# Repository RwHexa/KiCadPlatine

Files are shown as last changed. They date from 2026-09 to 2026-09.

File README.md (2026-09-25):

# KiCadPlatine — Netzteil 230 V~ → +12 V, vollständig von einer KI entwickelt

Ein KiCad-8-Projekt für ein einfaches Linearnetzteil mit dem Festspannungsregler **7812**.
Das Besondere daran ist nicht die Schaltung — die steht in jedem Lehrbuch — sondern **wie
sie entstanden ist**: Der komplette Entwurf wurde von der KI **Claude** (Anthropic,
über Claude Code) erstellt. Vorgabe war ein einziges Bild.

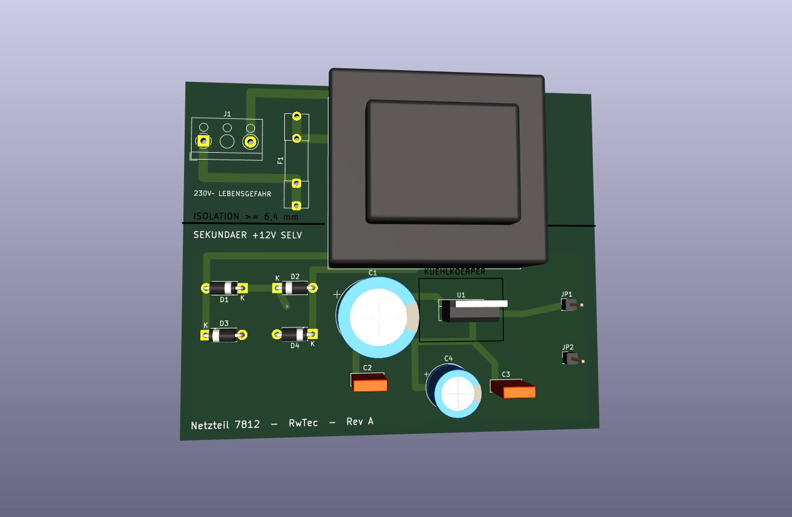
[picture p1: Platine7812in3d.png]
Fertige Platine in der 3D-Ansicht von KiCad


---

## 🤖 Was die KI gemacht hat

**Alles zwischen Vorgabe und fertigen Produktionsdaten — in rund 55 Minuten:**

| Schritt | Ergebnis |
|---|---|
| Bibliotheken analysiert | Symbole und Footprints geprüft statt geraten |
| **Schaltplan** entworfen | 14 Bauteile, 8 Netze, `.kicad_sch` |
| **Bauteilwerte berechnet** | Trafo, Ladeelko, Sicherung, Verlustleistung |
| **Platine layoutet** | Bauteilplatzierung, Primär/Sekundär getrennt |
| **Vollständig geroutet** | 50 Leiterbahnsegmente, nur 2 Durchkontaktierungen |
| **Massefläche** angelegt | bewusst nur sekundärseitig |
| **Sicherheitsregel** definiert | eigene DRC-Regel: 6,4 mm Kriechstrecke |
| **Fehler gefunden und behoben** | u. a. zwei echte Kurzschlüsse |
| **Produktionsdaten** erzeugt | Gerber, Bohrdatei, Stückliste, PDFs |

**Was der Mensch beigetragen hat:** das Vorgabebild, zwei Entscheidungen
(Trafo auf der Platine statt extern, 0,5 A Ausgangsstrom) sowie Durchsicht und Freigabe.
Keine einzige Leiterbahn wurde von Hand gezogen.

Der Entwurf entstand **nicht durch Klicken in der KiCad-Oberfläche**, sondern über
Python-Generatorskripte (`kiutils`, `pcbnew`, `kicad-cli`). KiCad selbst diente als
Prüfinstanz. Das ganze Projekt lässt sich mit einem Befehl reproduzieren:

```bash
python build_all.py
```

## 📋 Die Vorgabe

Mehr als dieses Bild und der Satz *„möchte mit KiCad eine Platine gebaut haben mit
Festspannungsregler 7812 sowie in der Bilddatei beschrieben"* gab es nicht:

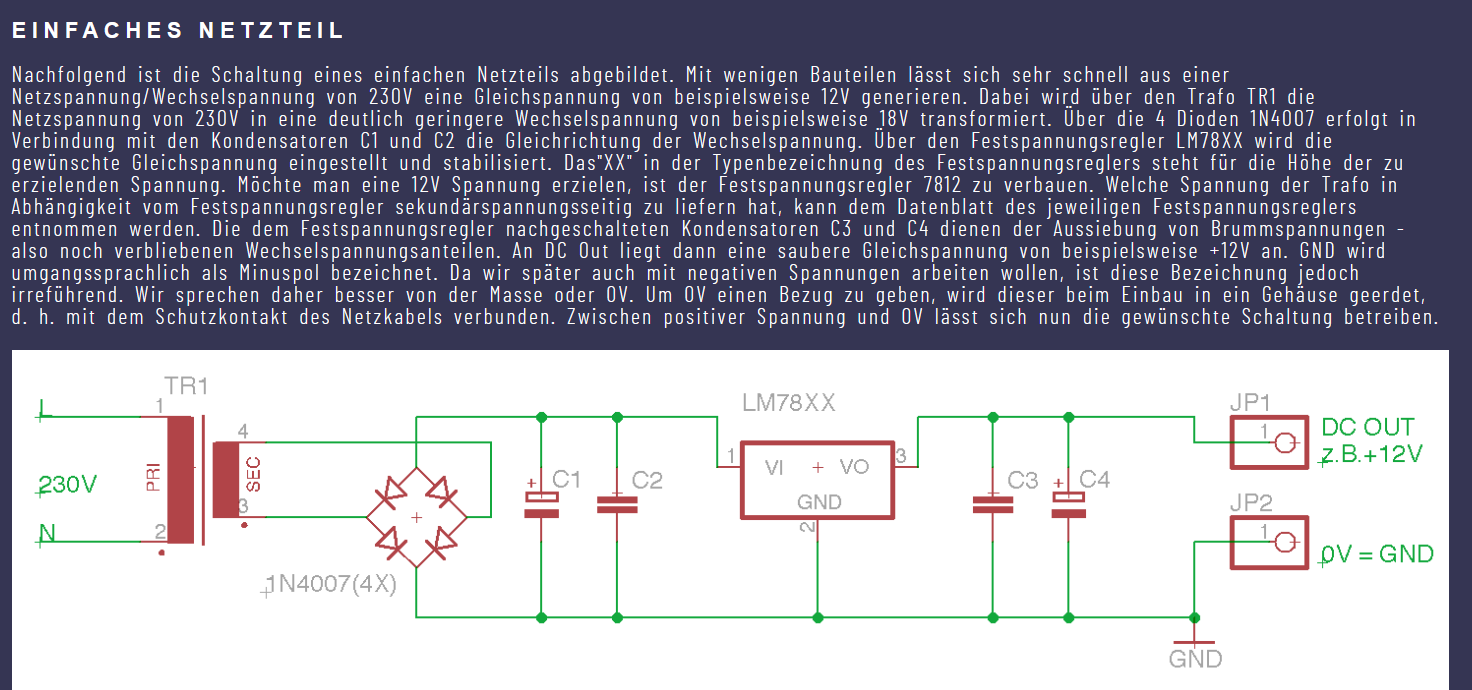
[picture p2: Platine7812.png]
Vorgabe: Schaltbild des einfachen Netzteils


## ✅ Geprüfter Stand

| Prüfung | Ergebnis |
|---|---|
| ERC (Schaltplanprüfung) | **0 Verstöße** |
| DRC (Designregelprüfung) | **0 Verstöße**, 0 unverbundene Anschlüsse |
| Kriechstrecke Primär ↔ Sekundär | **≥ 6,4 mm**, per eigener Regel nachgerechnet |
| Platinengröße | **92,2 × 77,2 mm**, 2 Lagen, bedrahtet (THT) |

Die Prüfberichte [`erc.rpt`](Platine7812/erc.rpt) und [`drc.rpt`](Platine7812/drc.rpt)
liegen im Repository — der Stand ist also nachprüfbar, nicht nur behauptet.

Bewusst unter 100 × 100 mm: Unterhalb dieser Grenze fertigen die üblichen Anbieter
deutlich günstiger. Dafür wanderte die gesamte Sekundärseite unter den Trafo.

## 🔬 Was die KI beim Prüfen gefunden hat

Der interessanteste Teil des Projekts. KiCads Prüfwerkzeuge deckten Fehler auf, die im
Layout wie normale Linien aussehen:

- **Zwei echte Kurzschlüsse** — je eine Leiterbahn lief mitten durch ein fremdes Lötauge
  (Phase durch den Neutralleiter-Anschluss, Masse durch den Reglereingang).
- **Netzlose „Geisterpads"** — der mitgelieferte KiCad-Trafo-Footprint legt 12 Kupferpads
  an, benennt aber nur 4. Die übrigen 8 wären blanke Kupferinseln direkt neben 230 V~
  geworden. Daraus wurde ein eigener, sauberer 4-Pad-Footprint abgeleitet.
- **Zu enge Abstände bei Netzspannung** — die Netzklemme wurde daraufhin von 5,08 mm auf
  10 mm Raster getauscht.

## 💡 Zwei Werte, die von der Vorlage abweichen

Die KI hat nachgerechnet und zwei Angaben des Vorlagentexts bewusst geändert:

**Sekundärspannung 15 V~ statt 18 V~**

```
15 V~ → Scheitelwert 15 · √2                          = 21,2 V
        − 2 Diodenflussspannungen (2 · 0,7 V)         = 19,8 V
        − Brummspannung I·t/C = 0,5 A · 10 ms / 2200 µF = 2,3 V
        → am Reglereingang bleiben                    ≈ 17,5 V
```

Der 7812 braucht mindestens 14 V — 3,5 V Reserve bleiben. Die überschüssige Spannung
verheizt der Regler: mit 15 V~ sind das **3,3 W**, mit 18 V~ wären es **5,5 W** gewesen.

**Trafo 15 VA statt 10 VA** — bei Gleichrichtung mit Ladeelko fließt der Strom in kurzen
Spitzen; der Trafo-Effektivstrom ist rund 1,6…1,8 × der Gleichstrom. Für 0,5 A DC sind das
ca. 0,85 A. Ein 10-VA-Typ liefert bei 15 V nur 0,67 A und wäre überlastet.

## 📦 Inhalt

```
Platine7812/
  Platine7812.kicad_sch     Schaltplan
  Platine7812.kicad_pcb     Leiterplatte, fertig geroutet
  Platine7812.kicad_dru     eigene DRC-Regel (6,4 mm Isolation)
  Platine7812.pretty/       projekteigener Trafo-Footprint
  fertigung/                Gerber, Bohrdatei, ZIP, Stückliste, PDFs
  erc.rpt · drc.rpt         Prüfberichte
  README.md                 technische Doku mit Auslegungsrechnung

  build_all.py              erzeugt das komplette Projekt neu
  build_schematic.py        Schaltplan-Generator
  build_pcb.py              Platinen-Generator (Platzierung + Routing)
  make_trafo_footprint.py   eigener Trafo-Footprint
  setup_project.py          Netzklassen
  make_fabrication.py       Produktionsdateien

PlatineKi.md                Werkstattbericht über die Entstehung
```

Die technischen Details stehen in [`Platine7812/README.md`](Platine7812/README.md),
die Entstehungsgeschichte in [`PlatineKi.md`](PlatineKi.md).

## ⚠️ Sicherheitshinweis

> Die **Primärseite dieser Platine führt Netzspannung (230 V~)**. Nachbau, Inbetriebnahme
> und Messung nur durch entsprechend qualifizierte Personen, mit Trenntrafo und niemals bei
> offenem Gehäuse. Primär- und Sekundärseite sind galvanisch getrennt (SELV am Ausgang).

## 🔧 Vor einem Nachbau zu prüfen

1. **Trafo-Anschlussmaße** gegen das Datenblatt des tatsächlich beschafften 15-VA-Trafos
   abgleichen. Der Footprint ist vom generischen KiCad-Trafo 37 × 44 mm abgeleitet; nach
   oben sind nur 2,4 mm Luft zur Platinenkante.
2. **Kühlkörper** für U1 aussuchen (≤ 15 K/W). Die Fläche von 19 × 14 mm ist freigehalten.
   Ohne Kühlkörper schaltet der 7812 bei 3,3 W thermisch ab.

Das Projekt ist geprüft, aber **noch nicht als Hardware aufgebaut**.

## 📄 Lizenz

[MIT](LICENSE) — die Lizenz gilt für **alle Bestandteile** dieses Repositorys: die
Generatorskripte, die KiCad-Entwurfsdateien und die Produktionsdaten. Nachbauen,
verändern und weitergeben sind ausdrücklich erwünscht, auch kommerziell; der
Copyright-Hinweis muss erhalten bleiben.

Wie in der MIT-Lizenz festgehalten, erfolgt die Weitergabe **ohne jede Gewährleistung**.
Das ist hier mehr als eine Formalie: Die Platine führt Netzspannung und ist bislang
geprüft, aber nicht als Hardware aufgebaut. Wer sie nachbaut, trägt die Verantwortung
für die eigene Ausführung — siehe Sicherheitshinweis oben.

---

*KiCad 8.0.8 · kiutils / pcbnew / kicad-cli · Entwurf: Claude (Anthropic) via Claude Code · Rw*

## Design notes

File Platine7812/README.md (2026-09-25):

# Platine7812 — einfaches Netzteil 230 V~ → +12 V DC

KiCad-8-Projekt nach dem Referenz-Schaltbild: Printtrafo **TR1** → Brücken­gleich­richter
aus **4 × 1N4007** → Siebung **C1/C2** → Festspannungsregler **LM7812** → **C3/C4** →
Ausgangsklemmen **JP1 (+12 V)** und **JP2 (0 V = GND)**.

> ⚠️ **LEBENSGEFAHR:** Die **Primärseite führt Netzspannung (230 V~)**. Primär- und
> Sekundärseite sind galvanisch getrennt (SELV am Ausgang). Aufbau, Inbetriebnahme und
> Messung nur durch qualifizierte Personen, Trenntrafo verwenden, Platine nie offen
> betreiben. Der 0-V-Anschluss wird beim Einbau ins Gehäuse mit dem Schutzkontakt verbunden.

## Stand

| Prüfung | Ergebnis |
|---|---|
| ERC (Schaltplan) | **0 Verstöße** |
| DRC (Leiterplatte) | **0 Verstöße**, **0 unverbundene Pads** |
| Kriechstrecke Primär↔Sekundär | **≥ 6,4 mm**, per eigener DRC-Regel nachgerechnet |
| Platinengröße | **92,2 × 77,2 mm**, 2 Lagen, THT |

Die Platine ist **vollständig geroutet** (50 Leiterbahnsegmente, 2 Durchkontaktierungen)
und hat eine gefüllte Massefläche auf der Rückseite — ausschließlich auf der
Sekundärseite, damit unter den netzspannungsführenden Bahnen kein Kupfer liegt.

## Stückliste

| Ref | Wert | Bauform / Footprint |
|---|---|---|
| TR1 | 230 V / 15 V, **15 VA** | Printtrafo, Körper 37 × 44 mm, 4 Pins |
| F1 | **T 160 mA / 250 V** | Feinsicherung 5 × 20 mm mit Printhalter, hochkant |
| J1 | Netzeingang L/N | Schraubklemme, **10 mm Raster** |
| D1–D4 | 1N4007 | DO-41, liegend, Raster 7,62 mm |
| C1 | 2200 µF / 35 V | Elko radial, Ø 16 mm, Raster 7,5 mm |
| C2 | 100 nF / 100 V | Folie, Raster 5 mm |
| U1 | **LM7812** | TO-220 stehend, **Kühlkörper erforderlich** |
| C3 | 100 nF / 50 V | Folie, Raster 5 mm |
| C4 | 100 µF / 25 V | Elko radial, Ø 10 mm, Raster 5 mm |
| JP1 / JP2 | +12 V / 0 V | je 1 Stift, Raster 2,54 mm |

## Auslegung — warum diese Werte

**Sekundärspannung 15 V~ (nicht 18 V~).** Der Text zum Referenzbild nennt 18 V als
Beispiel. 15 V reichen aber und halbieren fast die Verlustwärme:

```
15 V~ → Scheitelwert      15 · √2        = 21,2 V
        − 2 Diodenflussspannungen (2 · 0,7 V) = 19,8 V
        − Brummspannung  ΔU = I·t/C = 0,5 A · 10 ms / 2200 µF = 2,3 V
        → Minimum am Reglereingang            ≈ 17,5 V
```

Der 7812 braucht mindestens 14 V am Eingang (12 V + 2 V Dropout) — **3,5 V Reserve**.
Verlustleistung am Regler: `(18,6 V − 12 V) · 0,5 A ≈ 3,3 W`.
Mit 18 V~ wären es **5,5 W** gewesen.

**Kühlkörper ist Pflicht.** Bei 3,3 W und 40 °C Umgebung wird ein Kühlkörper mit
**≤ 15 K/W** gebraucht (Sperrschicht bleibt dann bei rund 105 °C). Auf der Platine ist
dafür eine Fläche von **19 × 14 mm** hinter U1 freigehalten und auf der Lage `Dwgs.User`
markiert. Ohne Kühlkörper schaltet der 7812 thermisch ab.

**Trafo 15 VA, nicht 10 VA.** Bei Gleichrichtung mit Ladeelko fließt der Strom in kurzen
Spitzen; der Trafo-Effektivstrom ist rund **1,6…1,8 × der Gleichstrom**. Für 0,5 A DC sind
das ca. 0,85 A — ein 10-VA-Typ liefert bei 15 V nur 0,67 A und wäre überlastet.
15 VA / 15 V = 1,0 A reicht mit Reserve.

**Sicherung.** Primär-Nennstrom `15 VA / 230 V = 65 mA`, träge Sicherung mit etwa dem
doppelten Wert → **T 160 mA**.

## Aufbau der Leiterplatte

**Primärseite oben** (y < 86 mm): J1 → F1 → TR1-Primärwicklung.
**Sekundärseite unten** (y > 90 mm): Brücke → C1/C2 → U1 → C3/C4 → JP1/JP2.
Dazwischen liegt die **Isolationsbarriere**; sie ist auf `Dwgs.User` eingezeichnet und
wird bauartbedingt nur vom Trafo selbst überbrückt (Pin-Reihenabstand 25,4 mm).

**Kreuzungsfreie Brückenanordnung.** D1 und D4 sind um 180° gedreht. Dadurch liegen die
beiden Kathoden (VRAW) innen nebeneinander und die beiden GND-Anoden ebenfalls:

```
AC1 --|<|-- VRAW   VRAW --|<|-- AC2     obere Reihe (D1 gedreht, D2)
AC1 --|<|-- GND    GND  --|<|-- AC2     untere Reihe (D3, D4 gedreht)
```

Die Brücke selbst braucht damit keine einzige Kreuzung. Nur VRAW muss die AC2-Bahn
queren — das erledigen zwei Durchkontaktierungen im freien Korridor zwischen den
Diodenreihen. GND läuft komplett auf der Rückseite und kann deshalb nichts kreuzen.

## Dateien

| Datei | Inhalt |
|---|---|
| `Platine7812.kicad_sch` | Schaltplan |
| `Platine7812.kicad_pcb` | Leiterplatte, geroutet |
| `Platine7812.kicad_pro` | Projektdatei inkl. Netzklassen |
| `Platine7812.kicad_dru` | **eigene DRC-Regel: 6,4 mm Primär ↔ Sekundär** |
| `Platine7812.net` | Netzliste (aus dem Schaltplan erzeugt) |
| `Platine7812.pretty/` | projekteigener Trafo-Footprint |
| `fertigung/` | Gerber, Bohrdateien, ZIP, Stückliste, PDFs |
| `erc.rpt`, `drc.rpt` | Prüfberichte |

### Generatorskripte

Das Projekt wird **vollständig aus Skripten erzeugt**; die Netzliste ist die einzige
Quelle der Wahrheit für die Leiterplatte (kein manueller Netzlisten-Import nötig).

```bash
python build_all.py
```

Das durchläuft der Reihe nach:

| Schritt | Skript | Ergebnis |
|---|---|---|
| 1 | `make_trafo_footprint.py` | Trafo-Footprint + `fp-lib-table` |
| 2 | `build_schematic.py` | `.kicad_sch` |
| 3 | `kicad-cli sch erc` | `erc.rpt` |
| 4 | `kicad-cli sch export netlist` | `.net` |
| 5 | `build_pcb.py` | `.kicad_pcb` (platziert, geroutet, Zone gefüllt) |
| 6 | `setup_project.py` | Netzklassen in `.kicad_pro` |
| 7 | `kicad-cli pcb drc` | `drc.rpt` |

Fertigungsdaten danach mit:

```bash
python make_fabrication.py
```

## Stolpersteine, die hier gelöst sind

1. **`LM7812_TO220` hat keine eigenen Pins** — das Symbol erbt sie per `extends` von
   `LM7805_TO220`. Wird es unverändert eingebettet, zeichnet Eeschema ein leeres Kästchen.
   `build_schematic.py` klopft es flach und schreibt die Unit-Namen um.
2. **Der KiCad-Trafo-Footprint hat Geisterpads.** `Transformer_THT:Transformer_37x44` legt
   12 Kupferpads an, nummeriert aber nur 4. Die 8 netzlosen Pads wären blanke Kupferinseln
   neben 230 V~. `make_trafo_footprint.py` leitet einen sauberen 4-Pad-Footprint ab.
3. **`kicad-cli` überschreibt die `.kicad_pro`** und wirft dabei eigene Netzklassen weg.
   Deshalb läuft `setup_project.py` immer **als letzter Schritt**.
4. **`ZONE_FILLER` stürzt** auf einem frisch erzeugten Board ab (Segfault). Auf einem
   *geladenen* Board mit `BuildConnectivity()` läuft er durch — `build_pcb.py` macht
   deshalb den Umweg Speichern → Laden → Füllen → Speichern. Ohne das bliebe die
   Massefläche in den Gerber-Dateien leer.
5. **Bohrdateien werden nicht mitgeplottet.** `export gerbers` liefert keine `.drl`;
   `make_fabrication.py` ruft `export drill` separat auf und bricht ab, wenn die
   Bohrdatei fehlt — ein ZIP ohne `.drl` ist beim Fertiger unbrauchbar.

## Vor dem Bestellen bitte prüfen

1. **Trafo-Footprint gegen das Datenblatt abgleichen.** Der Footprint ist vom generischen
   KiCad-Trafo 37 × 44 mm abgeleitet: Primärpads bei x = 0 / 20,32 mm, Sekundärpads bei
   x = ±5,08 mm, Reihenabstand 25,4 mm. **Rastermaß und Pinbelegung des tatsächlich
   beschafften Trafos prüfen** und notfalls in `make_trafo_footprint.py` anpassen.
2. **Kühlkörper aussuchen** (≤ 15 K/W) und prüfen, ob er in die freigehaltenen
   19 × 14 mm passt.
3. **Elko-Bauhöhen** gegen das geplante Gehäuse prüfen (C1 ist Ø 16 mm).
4. Die **Sicherung sitzt nur in der Phase (L)**. Für allpolige Trennung gehört ein
   zweipoliger Schalter vor die Platine.

---
*RwTec · 2026 · erstellt mit Claude Code aus dem Referenz-Schaltbild.*

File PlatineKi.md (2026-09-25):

# Platinenentwurf mit KiCad und Claude Code — ein Werkstattbericht

> **Kurzfassung:** Aus einem Schaltbild als Bilddatei ist in rund **55 Minuten** eine
> fertige, geprüfte Leiterplatte geworden: ein Netzteil 230 V~ → +12 V mit dem
> Festspannungsregler 7812. Vorgegeben waren ein Screenshot und ein erklärender Text —
> herausgekommen sind Schaltplan, geroutete Platine (92 × 77 mm, ==ERC 0, DRC 0==) und
> ein vollständiger Satz Produktionsdateien. Besonderheit: Der Entwurf entstand nicht
> durch Klicken in KiCad, sondern über **Generatorskripte**, und KiCad selbst diente als
> Prüfinstanz.

---

## 🧭 Die Vorgabe

Ausgangspunkt war ein Bild mit Schaltung und Beschreibung — das klassische
Lehrbuch-Netzteil:

Vorgabe: Schaltbild des einfachen Netzteils

Der Text dazu beschreibt den Signalweg: Der Trafo **TR1** setzt die Netzspannung von
230 V auf eine kleinere Wechselspannung herunter, vier Dioden **1N4007** richten sie
gleich, **C1/C2** sieben sie, der **LM78XX** stabilisiert auf die gewünschte
Gleichspannung, **C3/C4** bügeln Restbrummen glatt. Heraus kommen an **JP1/JP2** die
+12 V gegen Masse.

Meine Vorgabe an Claude Code war knapp: *„möchte mit KiCad eine Platine gebaut haben mit
Festspannungsregler 7812 sowie in der Bilddatei beschrieben"* — plus der Hinweis, dass
ich in KiCad bereits ein leeres Projekt **Platine7812** angelegt hatte.

---

## 📐 Zwei Rückfragen vorab

Bevor irgendetwas gebaut wurde, kamen zwei Fragen, die das Bild nicht beantwortet:

| Frage | Meine Entscheidung |
|---|---|
| Trafo **auf** der Platine oder extern? | auf der Platine — wie im Bild |
| Welcher Ausgangsstrom? | ca. **0,5 A** |

Das war gut investiert: An diesen zwei Antworten hängen Platinengröße, Bauteilwerte,
Kühlkörper und die Sicherheitsabstände zur Netzspannung.

---

## 🛠️ Die Umsetzung

Der eigentliche Kniff: Statt Bauteile in KiCad zusammenzuklicken, schrieb Claude Code
**Python-Skripte, die das Projekt erzeugen**. Der Ablauf in groben Zügen:

1. **🔬 Bibliotheken inspizieren.** Erst nachsehen, wie die Bauteile in KiCad wirklich
   heißen und wo ihre Anschlüsse liegen — nicht raten.
2. **📐 Schaltplan erzeugen.** Jedes Bauteil bekommt ein kurzes Leitungsstück mit einem
   Netz-Namen. Gleiche Namen sind elektrisch verbunden — das ist robuster, als Drähte zu
   zeichnen.
3. **✅ ERC laufen lassen.** KiCads Schaltplanprüfung meldete erst 10 Verstöße, nach
   Korrektur **0**.
4. **📦 Netzliste exportieren.** Sie ist ab hier die ==einzige Quelle der Wahrheit== —
   die Platine wird direkt aus ihr aufgebaut, nicht von Hand nachgepflegt.
5. **🔧 Platine bauen.** Bauteile setzen, Leiterbahnen ziehen, Massefläche füllen.
6. **✅ DRC laufen lassen** — und zwar mehrfach, siehe unten.

Am Ende steht ein einziger Befehl, der alles reproduziert:

```
python build_all.py
```

Wenn ich morgen den Elko C1 auf 3300 µF ändern will, ändere ich eine Zeile und lasse das
Skript laufen. Schaltplan, Netzliste, Platine und Prüfberichte sind danach wieder
konsistent — ein Abgleich von Hand entfällt.

---

## 🔬 Was die Prüfungen gefunden haben

Das ist der Teil, der mich am meisten überzeugt hat. KiCads eigene Prüfwerkzeuge haben
Fehler gefunden, die man im Layout leicht übersieht:

- ⚠️ **Zwei echte Kurzschlüsse.** Eine Leiterbahn lief mitten durch ein fremdes Lötauge
  — einmal die Phase durch den Neutralleiter-Anschluss, einmal Masse durch den
  Reglereingang. Auf dem Bildschirm sieht so etwas aus wie eine normale gerade Linie.
- ⚠️ **Geisterpads am Trafo.** Der mitgelieferte KiCad-Trafo-Footprint legt 12 Kupferpads
  an, benennt aber nur 4. Die übrigen 8 hätten als blanke Kupferinseln ==direkt neben
  230 V~== auf der fertigen Platine gesessen. Claude Code hat daraus einen eigenen,
  sauberen Footprint mit genau 4 Anschlüssen abgeleitet.
- ⚠️ **Zu enge Abstände bei Netzspannung.** Dafür wurde eine eigene Entwurfsregel
  hinterlegt: *mindestens 6,4 mm zwischen Primär- und Sekundärkreis*. KiCad rechnet das
  jetzt bei jedem Durchlauf nach, statt dass man sich auf eine gezeichnete Trennlinie
  verlässt. Auch die Netzklemme wurde deshalb von 5,08 mm auf **10 mm Raster** getauscht.

> Ein Layout, das „richtig aussieht", ist nicht geprüft. Erst ERC und DRC machen daraus
> eine belastbare Aussage.

---

## 💡 Zwei Werte, die vom Bild abweichen

Beim Nachrechnen fielen zwei Punkte auf, die bewusst anders umgesetzt wurden:

**🔑 Sekundärspannung 15 V~ statt der im Text genannten 18 V~.** Die Rechnung:

```
15 V~ → Scheitelwert 15 · √2                     = 21,2 V
        − 2 Diodenflussspannungen (2 · 0,7 V)    = 19,8 V
        − Brummspannung  I·t/C = 0,5 A · 10 ms / 2200 µF = 2,3 V
        → am Reglereingang bleiben               ≈ 17,5 V
```

Der 7812 braucht mindestens 14 V — es bleiben **3,5 V Reserve**. Die überschüssige
Spannung verheizt der Regler: Mit 15 V~ sind das **3,3 W**, mit 18 V~ wären es **5,5 W**
gewesen.

**🔑 Trafo 15 VA statt 10 VA.** Bei Gleichrichtung mit Ladeelko fließt der Strom nicht
gleichmäßig, sondern in kurzen Spitzen. Der Effektivstrom im Trafo ist deshalb rund
**1,6- bis 1,8-mal so hoch** wie der Gleichstrom am Ausgang — für 0,5 A also etwa 0,85 A.
Ein 10-VA-Trafo liefert bei 15 V nur 0,67 A und wäre überlastet gewesen. Die Sicherung
wurde entsprechend auf T 160 mA angepasst.

---

## 📦 Das Endprodukt

Fertige Platine in der 3D-Ansicht von KiCad

Oben die **Primärseite** mit Netzklemme, Feinsicherung (hochkant, spart 16 mm Breite) und
Trafo. Darunter die durchgezogene **Isolationsbarriere**. Unten die **Sekundärseite** mit
Brückengleichrichter, Ladeelko, Regler samt freigehaltener Kühlkörperfläche und den
beiden Ausgangsstiften.

| Kennwert | Wert |
|---|---|
| Größe | 92,2 × 77,2 mm, 2 Lagen, bedrahtet (THT) |
| ERC / DRC | **0 / 0 Verstöße**, 0 unverbundene Anschlüsse |
| Kriechstrecke Primär ↔ Sekundär | ≥ 6,4 mm, per Regel nachgerechnet |
| Leiterbahnen | 50 Segmente, nur 2 Durchkontaktierungen |

Dass die Platine **unter 100 × 100 mm** bleibt, war Absicht: Unterhalb dieser Grenze
fertigen die üblichen Anbieter deutlich günstiger. Dafür wanderte die gesamte
Sekundärseite unter den Trafo.

**🎯 Kreuzungsfreie Brücke.** Ein hübsches Detail: Durch Drehen von zwei der vier Dioden
um 180° liegen die Anschlüsse so, dass der Gleichrichter ganz ohne Leitungskreuzung
auskommt:

```
AC1 --|<|-- VRAW   VRAW --|<|-- AC2     obere Reihe
AC1 --|<|-- GND    GND  --|<|-- AC2     untere Reihe
```

### Produktionsdateien

Im Ordner `Platine7812/fertigung` liegt alles Nötige:

| Datei | Zweck |
|---|---|
| `Platine7812_Fertigung.zip` | **das, was der Fertiger bekommt** — 7 Gerber-Lagen + Bohrdatei |
| `Platine7812.drl` | Bohrdatei (Excellon) |
| `Platine7812_BOM.csv` | Stückliste |
| `Platine7812_Schaltplan.pdf` | Schaltplan |
| `Platine7812_Bestueckung.pdf` | Bestückungsplan |

⚠️ Eine Falle, die hier bewusst abgesichert ist: KiCads „Plot"-Funktion erzeugt **nur die
Gerber-Dateien, nicht die Bohrdatei**. Ein ZIP ohne `.drl` ist beim Fertiger unbrauchbar.
Das Skript ruft den Bohrdatei-Export deshalb separat auf und bricht ab, wenn die Datei
fehlt.

---

## ⚠️ Was vor der Bestellung noch zu tun ist

1. **Trafo-Anschlussmaße prüfen.** Der Footprint ist vom generischen KiCad-Trafo
   37 × 44 mm abgeleitet. Sobald der reale 15-VA-Trafo da ist, gehört sein Datenblatt
   gegen die Pad-Abstände gehalten. Nach oben sind nur 2,4 mm Luft zur Platinenkante.
2. **Kühlkörper aussuchen** (≤ 15 K/W). Die Fläche von 19 × 14 mm ist freigehalten. Ohne
   Kühlkörper schaltet der 7812 bei 3,3 W thermisch ab.

---

## ✅ Fazit

Rund **55 Minuten** von der Bilddatei zur prüfbaren Platine — das Bemerkenswerte daran
ist weniger das Tempo als die **Nachvollziehbarkeit**. Jeder Schritt steckt in einem
Skript, jede Designentscheidung ist im Code kommentiert, und die Aussage „das passt"
kommt nicht aus dem Bauchgefühl, sondern aus KiCads eigenen Prüfwerkzeugen.

Für den Unterricht ist genau das der interessante Teil: Man kann zeigen, *warum* die
Netzklemme 10 mm Raster hat, *warum* 15 V~ besser sind als 18 V~ und *was* ein
Kurzschluss-Fund im DRC-Bericht bedeutet — und alles mit einem Befehl noch einmal
nachvollziehen.

> ⚠️ **Sicherheitshinweis:** Die Primärseite führt 230 V~. Aufbau und Messung nur durch
> qualifizierte Personen, mit Trenntrafo und niemals bei offenem Gehäuse.



*Erstellt: 2026-09-25 · KiCad 8.0.8 · kiutils / pcbnew / kicad-cli · Claude Code + Rw*

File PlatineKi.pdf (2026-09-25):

# Platinenentwurf mit KiCad und Claude Code — ein Werkstattbericht

Kurzfassung: Aus einem Schaltbild als Bilddatei ist in rund 55 Minuten eine
fertige, geprüfte Leiterplatte geworden: ein Netzteil 230 V~ → +12 V mit dem Festspannungsregler 7812. Vorgegeben waren ein Screenshot und ein erklärender Text — herausgekommen sind Schaltplan, geroutete Platine (92 × 77 mm, ==ERC 0, DRC 0==) und ein vollständiger Satz Produktionsdateien. Besonderheit: Der Entwurf entstand nicht
durch Klicken in KiCad, sondern über Generatorskripte, und KiCad selbst diente als Prüfinstanz.

## 🧭 Die Vorgabe

Ausgangspunkt war ein Bild mit Schaltung und Beschreibung — das klassische Lehrbuch-Netzteil:

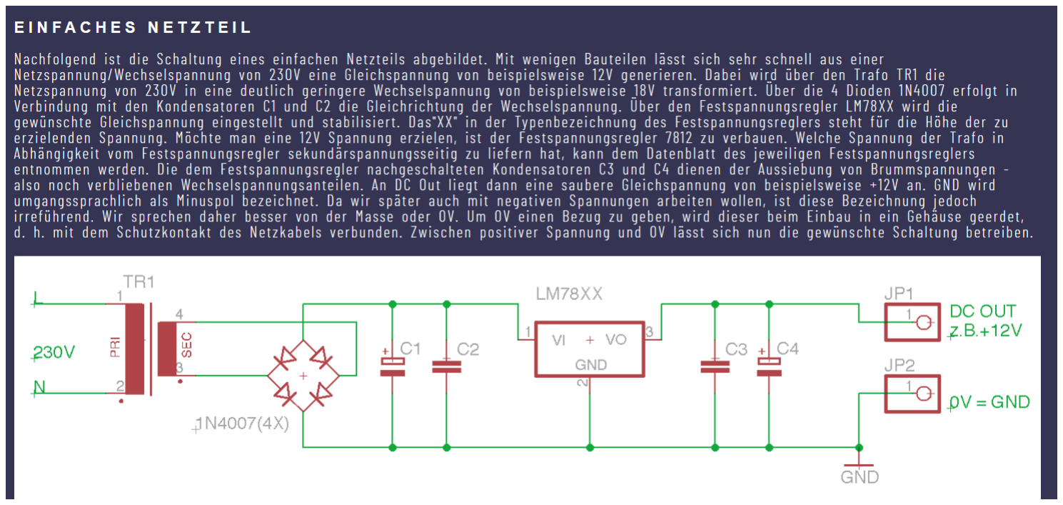
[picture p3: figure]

Der Text dazu beschreibt den Signalweg: Der Trafo TR1 setzt die Netzspannung von 230 V auf eine kleinere Wechselspannung herunter, vier Dioden 1N4007 richten sie gleich, C1/C2 sieben sie, der LM78XX stabilisiert auf die gewünschte
Gleichspannung, C3/C4 bügeln Restbrummen glatt. Heraus kommen an JP1/JP2 die
+12 V gegen Masse.

Meine Vorgabe an Claude Code war knapp: „möchte mit KiCad eine Platine gebaut haben mit Festspannungsregler 7812 sowie in der Bilddatei beschrieben" — plus der Hinweis, dass
ich in KiCad bereits ein leeres Projekt Platine7812 angelegt hatte.

## 📐 Zwei Rückfragen vorab

Bevor irgendetwas gebaut wurde, kamen zwei Fragen, die das Bild nicht beantwortet:

Frage | Meine Entscheidung

Trafo auf der Platine oder extern? auf der Platine — wie im Bild

Welcher Ausgangsstrom? | ca. 0,5 A

Das war gut investiert: An diesen zwei Antworten hängen Platinengröße, Bauteilwerte, Kühlkörper und die Sicherheitsabstände zur Netzspannung.

## 🛠 Die Umsetzung

Der eigentliche Kniff: Statt Bauteile in KiCad zusammenzuklicken, schrieb Claude Code Python-Skripte, die das Projekt erzeugen. Der Ablauf in groben Zügen:

1. 🔬 Bibliotheken inspizieren. Erst nachsehen, wie die Bauteile in KiCad wirklich
heißen und wo ihre Anschlüsse liegen — nicht raten.
2. 📐 Schaltplan erzeugen. Jedes Bauteil bekommt ein kurzes Leitungsstück mit einem Netz-Namen. Gleiche Namen sind elektrisch verbunden — das ist robuster, als Drähte zu zeichnen.
3. ✅ ERC laufen lassen. KiCads Schaltplanprüfung meldete erst 10 Verstöße, nach Korrektur 0.
4. 📦 Netzliste exportieren. Sie ist ab hier die ==einzige Quelle der Wahrheit== — die Platine wird direkt aus ihr aufgebaut, nicht von Hand nachgepflegt.
5. 🔧 Platine bauen. Bauteile setzen, Leiterbahnen ziehen, Massefläche füllen.
6. ✅ DRC laufen lassen — und zwar mehrfach, siehe unten.

Am Ende steht ein einziger Befehl, der alles reproduziert:

Wenn ich morgen den Elko C1 auf 3300 µF ändern will, ändere ich eine Zeile und lasse das Skript laufen. Schaltplan, Netzliste, Platine und Prüfberichte sind danach wieder konsistent — ein Abgleich von Hand entfällt.

## 🔬 Was die Prüfungen gefunden haben

Das ist der Teil, der mich am meisten überzeugt hat. KiCads eigene Prüfwerkzeuge haben Fehler gefunden, die man im Layout leicht übersieht:

⚠ Zwei echte Kurzschlüsse. Eine Leiterbahn lief mitten durch ein fremdes Lötauge — einmal die Phase durch den Neutralleiter-Anschluss, einmal Masse durch den Reglereingang. Auf dem Bildschirm sieht so etwas aus wie eine normale gerade Linie. ⚠ Geisterpads am Trafo. Der mitgelieferte KiCad-Trafo-Footprint legt 12 Kupferpads an, benennt aber nur 4. Die übrigen 8 hätten als blanke Kupferinseln ==direkt neben

230 V~== auf der fertigen Platine gesessen. Claude Code hat daraus einen eigenen, sauberen Footprint mit genau 4 Anschlüssen abgeleitet.
⚠ Zu enge Abstände bei Netzspannung. Dafür wurde eine eigene Entwurfsregel hinterlegt: mindestens 6,4 mm zwischen Primär- und Sekundärkreis. KiCad rechnet das jetzt bei jedem Durchlauf nach, statt dass man sich auf eine gezeichnete Trennlinie verlässt. Auch die Netzklemme wurde deshalb von 5,08 mm auf 10 mm Raster getauscht.

Ein Layout, das „richtig aussieht", ist nicht geprüft. Erst ERC und DRC machen daraus
eine belastbare Aussage.

## 💡 Zwei Werte, die vom Bild abweichen

Beim Nachrechnen fielen zwei Punkte auf, die bewusst anders umgesetzt wurden:

🔑 Sekundärspannung 15 V~ statt der im Text genannten 18 V~. Die Rechnung:

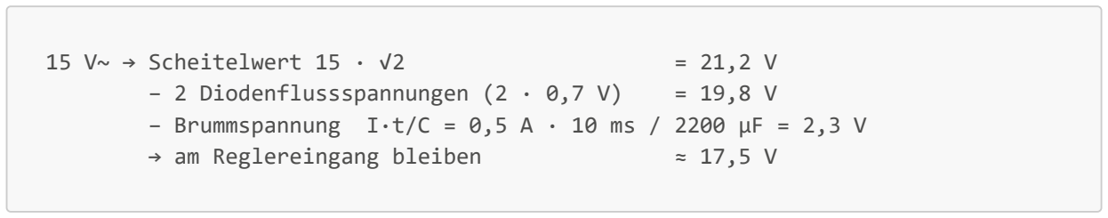
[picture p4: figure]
15 V~ → Scheitelwert 15 · √2; → am Reglereingang bleiben

− 2 Diodenflussspannungen (2 · 0,7 V) = 19,8 V
− Brummspannung I·t/C = 0,5 A · 10 ms / 2200 µF = 2,3 V

Der 7812 braucht mindestens 14 V — es bleiben 3,5 V Reserve. Die überschüssige Spannung verheizt der Regler: Mit 15 V~ sind das 3,3 W, mit 18 V~ wären es 5,5 W gewesen.

🔑 Trafo 15 VA statt 10 VA. Bei Gleichrichtung mit Ladeelko fließt der Strom nicht gleichmäßig, sondern in kurzen Spitzen. Der Effektivstrom im Trafo ist deshalb rund 1,6- bis 1,8-mal so hoch wie der Gleichstrom am Ausgang — für 0,5 A also etwa 0,85 A. Ein 10-VA-Trafo liefert bei 15 V nur 0,67 A und wäre überlastet gewesen. Die Sicherung wurde entsprechend auf T 160 mA angepasst.

## 📦 Das Endprodukt


Oben die Primärseite mit Netzklemme, Feinsicherung (hochkant, spart 16 mm Breite) und Trafo. Darunter die durchgezogene Isolationsbarriere. Unten die Sekundärseite mit Brückengleichrichter, Ladeelko, Regler samt freigehaltener Kühlkörperfläche und den beiden Ausgangsstiften.

Kennwert | Wert
Größe | 92,2 × 77,2 mm, 2 Lagen, bedrahtet (THT)
ERC / DRC | 0 / 0 Verstöße, 0 unverbundene Anschlüsse

Kriechstrecke Primär ↔ Sekundär ≥ 6,4 mm, per Regel nachgerechnet

Leiterbahnen | 50 Segmente, nur 2 Durchkontaktierungen

Dass die Platine unter 100 × 100 mm bleibt, war Absicht: Unterhalb dieser Grenze fertigen die üblichen Anbieter deutlich günstiger. Dafür wanderte die gesamte Sekundärseite unter den Trafo.

🎯 Kreuzungsfreie Brücke. Ein hübsches Detail: Durch Drehen von zwei der vier Dioden um 180° liegen die Anschlüsse so, dass der Gleichrichter ganz ohne Leitungskreuzung

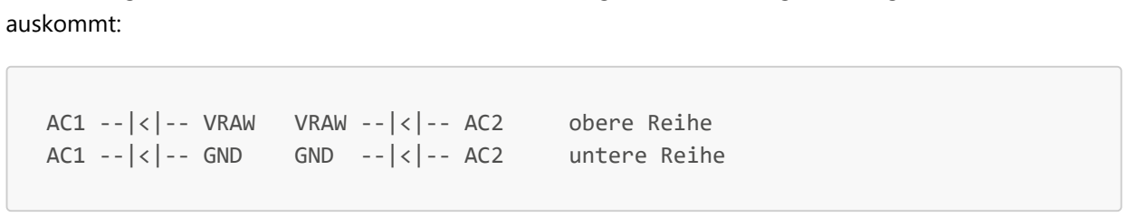
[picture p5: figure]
auskommt:; AC1 --|<|-- VRAW; VRAW --|<|-- AC2; obere Reihe; AC1 --|<|-- GND; GND --|<|-- AC2; untere Reihe

Produktionsdateien

Im Ordner Platine7812/fertigung liegt alles Nötige:

Datei | Zweck
Platine7812_Fertigung.zip | das, was der Fertiger bekommt — 7 Gerber-Lagen + Bohrdatei
Platine7812.drl | Bohrdatei (Excellon)
Platine7812_BOM.csv | Stückliste
Platine7812_Schaltplan.pdf | Schaltplan
Platine7812_Bestueckung.pdf | Bestückungsplan

⚠ Eine Falle, die hier bewusst abgesichert ist: KiCads „Plot"-Funktion erzeugt nur die Gerber-Dateien, nicht die Bohrdatei. Ein ZIP ohne .drl ist beim Fertiger unbrauchbar. Das Skript ruft den Bohrdatei-Export deshalb separat auf und bricht ab, wenn die Datei fehlt.

## ⚠ Was vor der Bestellung noch zu tun ist

1. Trafo-Anschlussmaße prüfen. Der Footprint ist vom generischen KiCad-Trafo
37 × 44 mm abgeleitet. Sobald der reale 15-VA-Trafo da ist, gehört sein Datenblatt gegen die Pad-Abstände gehalten. Nach oben sind nur 2,4 mm Luft zur Platinenkante.
2. Kühlkörper aussuchen (≤ 15 K/W). Die Fläche von 19 × 14 mm ist freigehalten. Ohne Kühlkörper schaltet der 7812 bei 3,3 W thermisch ab.

## ✅ Fazit

Rund 55 Minuten von der Bilddatei zur prüfbaren Platine — das Bemerkenswerte daran ist weniger das Tempo als die Nachvollziehbarkeit. Jeder Schritt steckt in einem Skript, jede Designentscheidung ist im Code kommentiert, und die Aussage „das passt" kommt nicht aus dem Bauchgefühl, sondern aus KiCads eigenen Prüfwerkzeugen.

Für den Unterricht ist genau das der interessante Teil: Man kann zeigen, warum die Netzklemme 10 mm Raster hat, warum 15 V~ besser sind als 18 V~ und was ein Kurzschluss-Fund im DRC-Bericht bedeutet — und alles mit einem Befehl noch einmal nachvollziehen.

⚠ Sicherheitshinweis: Die Primärseite führt 230 V~. Aufbau und Messung nur durch qualifizierte Personen, mit Trenntrafo und niemals bei offenem Gehäuse.

Erstellt: 2026-09-25 · KiCad 8.0.8 · kiutils / pcbnew / kicad-cli · Claude Code + Rw

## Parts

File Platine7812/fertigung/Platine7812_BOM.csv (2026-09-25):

Reference | Value | Footprint | QUANTITY
C1 | 2200uF/35V | Capacitor_THT:CP_Radial_D16.0mm_P7.50mm | 1
C2 | 100nF/100V | Capacitor_THT:C_Rect_L7.0mm_W2.5mm_P5.00mm | 1
C3 | 100nF/50V | Capacitor_THT:C_Rect_L7.0mm_W2.5mm_P5.00mm | 1
C4 | 100uF/25V | Capacitor_THT:CP_Radial_D10.0mm_P5.00mm | 1
D1-D4 | 1N4007 | Diode_THT:D_DO-41_SOD81_P7.62mm_Horizontal | 4
F1 | T 160mA / 250V | Fuse:Fuseholder_Clip-5x20mm_Littelfuse_111_Inline_P20.00x5.00mm_D1.05mm_Horizontal | 1
J1 | 230V~ L/N | TerminalBlock_RND:TerminalBlock_RND_205-00023_1x02_P10.00mm_Horizontal | 1
JP1 | DC OUT z.B. +12V | Connector_PinHeader_2.54mm:PinHeader_1x01_P2.54mm_Vertical | 1
JP2 | 0V = GND | Connector_PinHeader_2.54mm:PinHeader_1x01_P2.54mm_Vertical | 1
TR1 | 230V/15V 15VA | Platine7812:Trafo_Print_15VA_4pin | 1
U1 | LM7812 | Package_TO_SOT_THT:TO-220-3_Vertical | 1

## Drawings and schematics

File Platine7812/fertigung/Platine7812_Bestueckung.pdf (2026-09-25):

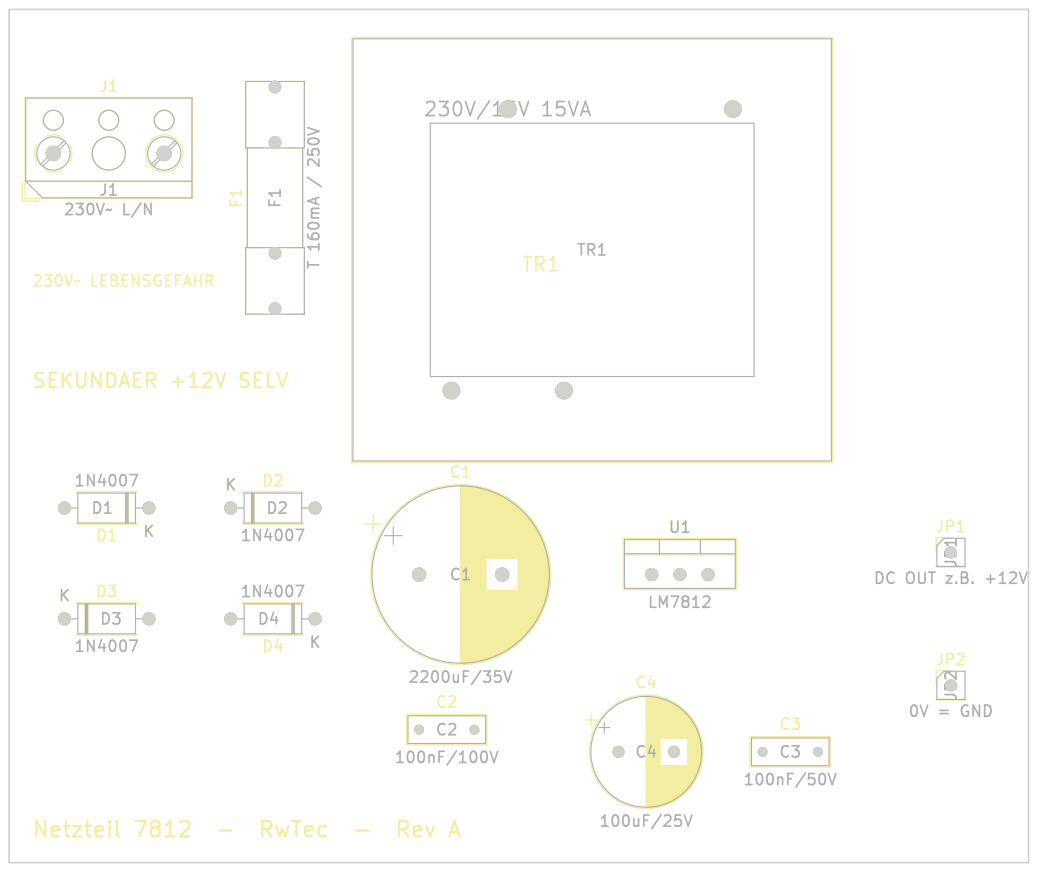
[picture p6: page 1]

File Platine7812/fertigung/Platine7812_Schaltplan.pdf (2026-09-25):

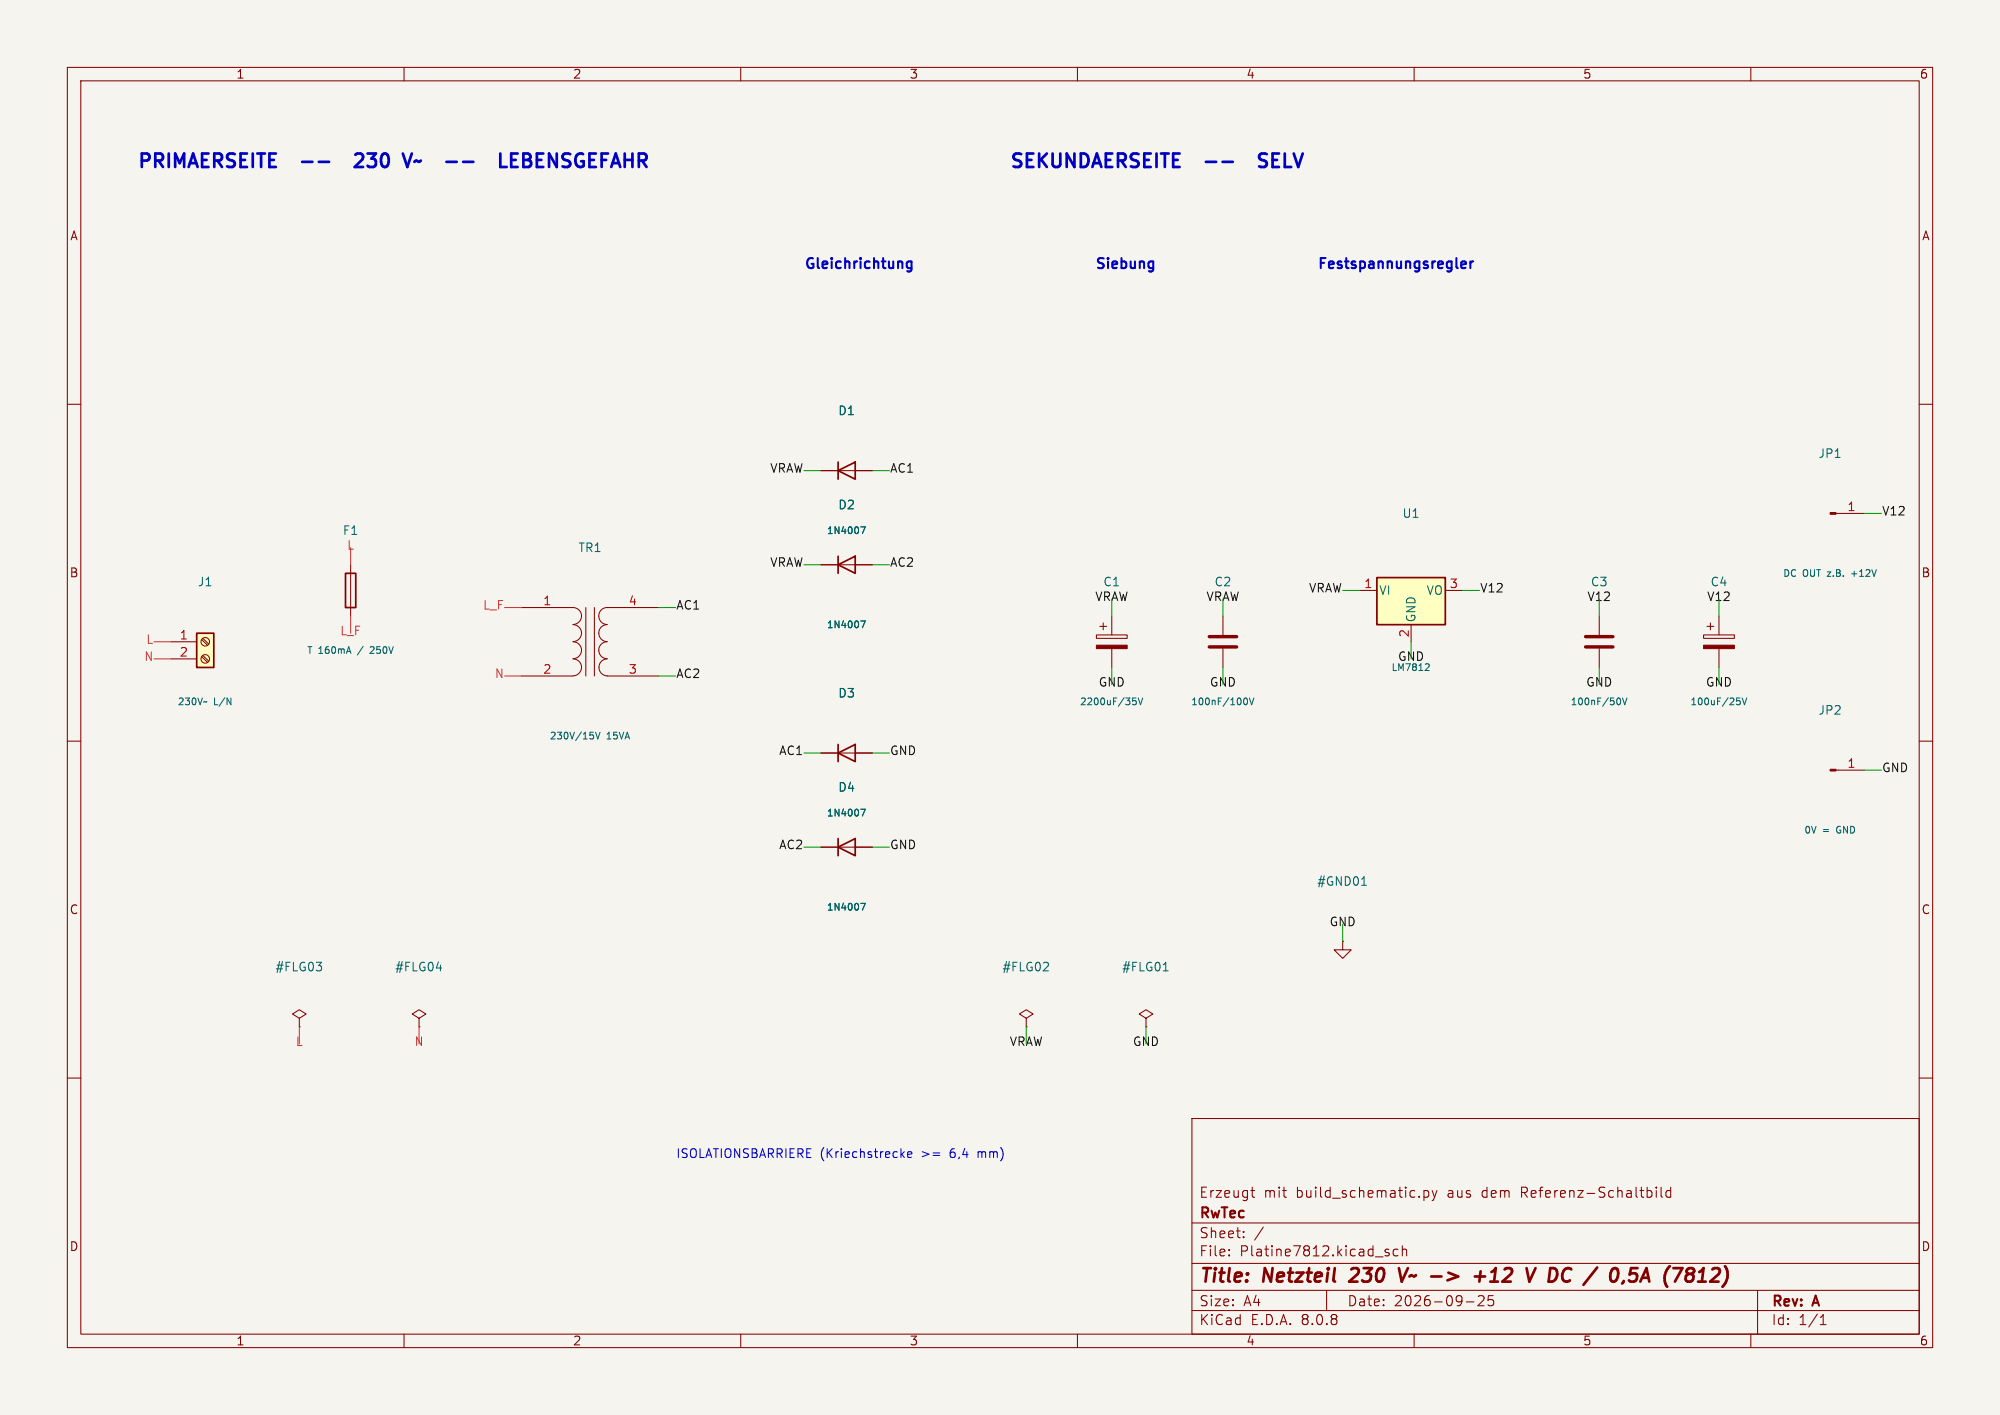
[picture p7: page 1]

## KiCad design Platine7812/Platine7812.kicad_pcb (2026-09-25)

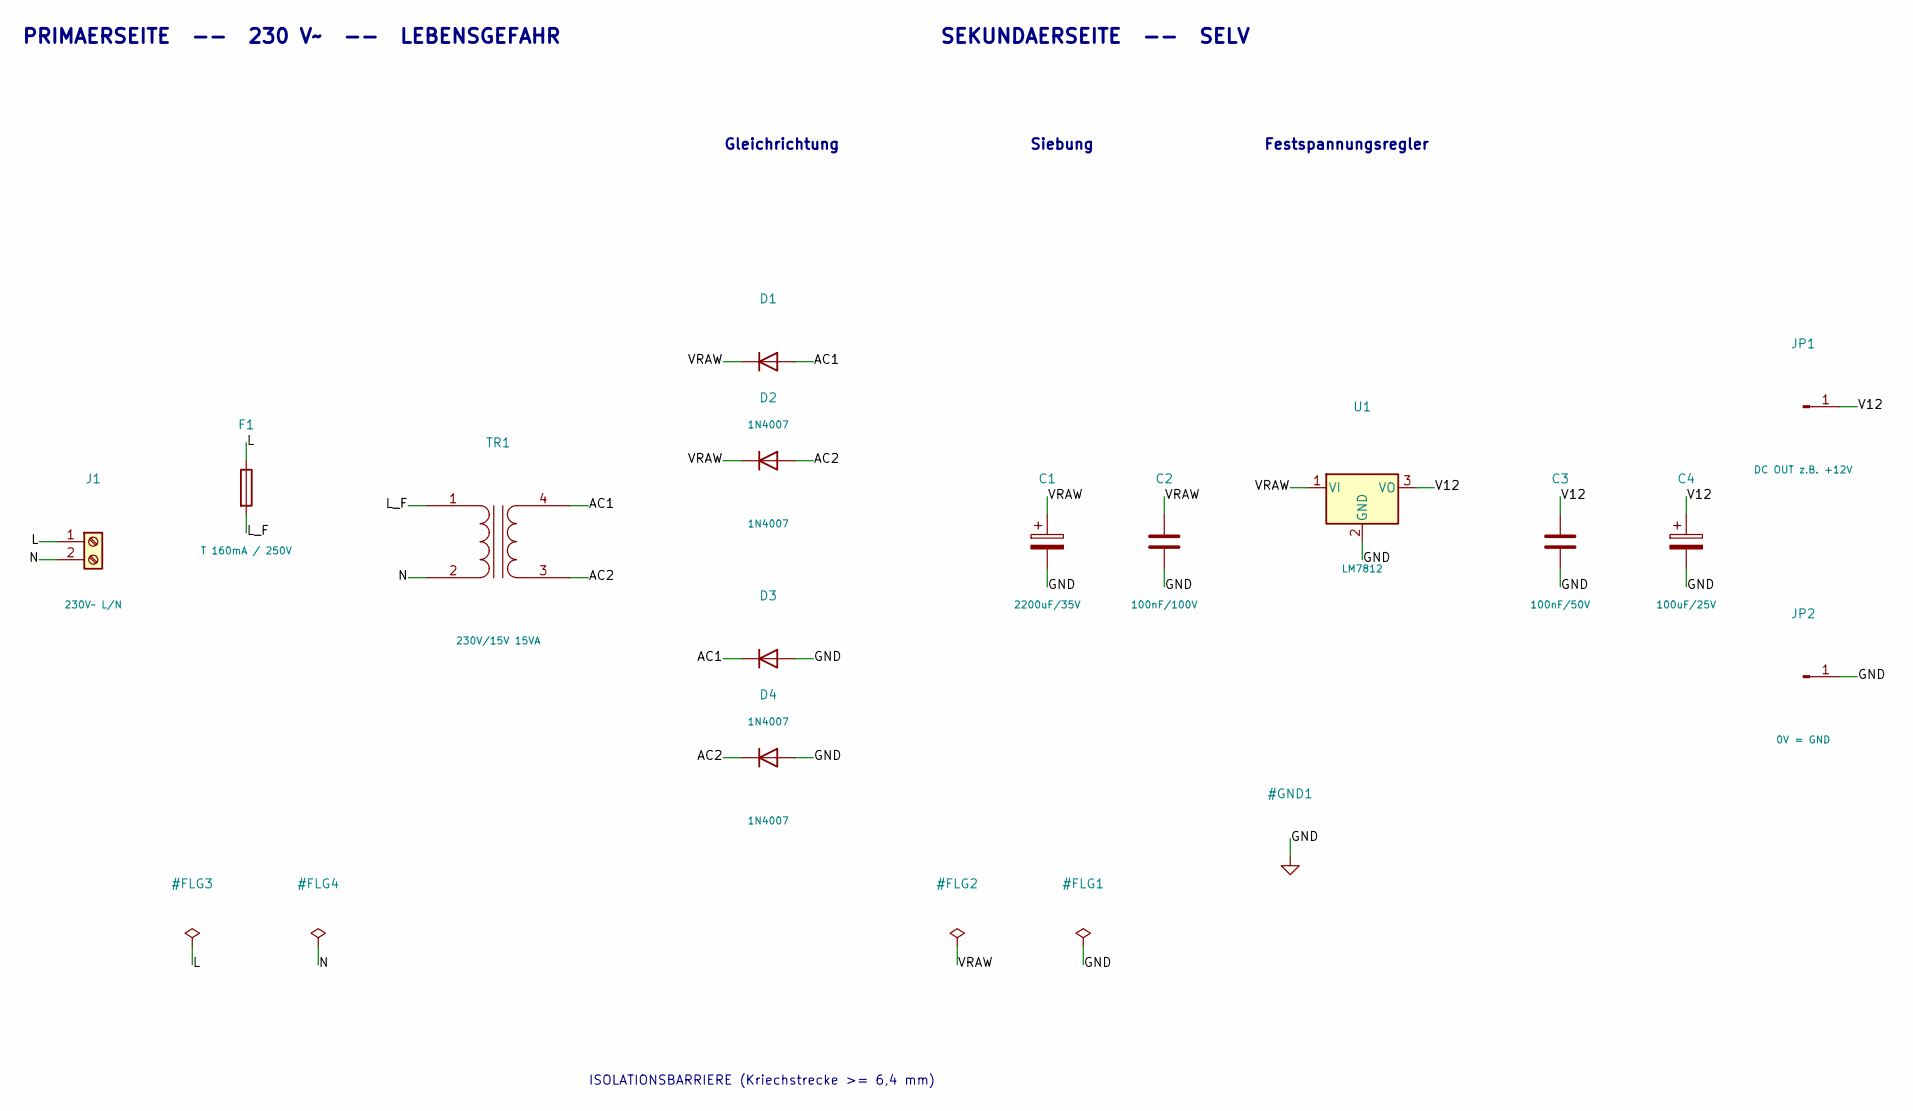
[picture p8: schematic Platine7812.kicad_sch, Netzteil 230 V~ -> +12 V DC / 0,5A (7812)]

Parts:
C1: 2200uF/35V; CP_Radial_D16.0mm_P7.50mm
C2: 100nF/100V; C_Rect_L7.0mm_W2.5mm_P5.00mm
C3: 100nF/50V; C_Rect_L7.0mm_W2.5mm_P5.00mm
C4: 100uF/25V; CP_Radial_D10.0mm_P5.00mm
D1, D2, D3, D4: 1N4007; D_DO-41_SOD81_P7.62mm_Horizontal
F1: T 160mA / 250V; Fuseholder_Clip-5x20mm_Littelfuse_111_Inline_P20.00x5.00mm_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
J1: 230V~ L/N; TerminalBlock_RND_205-00023_1x02_P10.00mm_Horizontal
JP1: DC OUT z.B. +12V; PinHeader_1x01_P2.54mm_Vertical
JP2: 0V = GND; PinHeader_1x01_P2.54mm_Vertical
TR1: 230V/15V 15VA; Trafo_Print_15VA_4pin
U1: LM7812; TO-220-3_Vertical

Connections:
/AC1: D1.2 (A), D3.1 (K), TR1.4 (SB)
/AC2: D2.2 (A), D4.1 (K), TR1.3 (SA)
/L: F1.1, J1.1
/L_F: F1.2, TR1.1 (AA)
/N: J1.2, TR1.2 (AB)
/V12: C3.1, C4.1, JP1.1, U1.3 (VO)
/VRAW: C1.1, C2.1, D1.1 (K), D2.1 (K), U1.1 (VI)
GND: C1.2, C2.2, C3.2, C4.2, D3.2 (A), D4.2 (A), JP2.1, U1.2 (GND)

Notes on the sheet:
PRIMAERSEITE -- 230 V~ -- LEBENSGEFAHR
Siebung
Festspannungsregler
ISOLATIONSBARRIERE (Kriechstrecke >= 6,4 mm)
SEKUNDAERSEITE -- SELV
Gleichrichtung

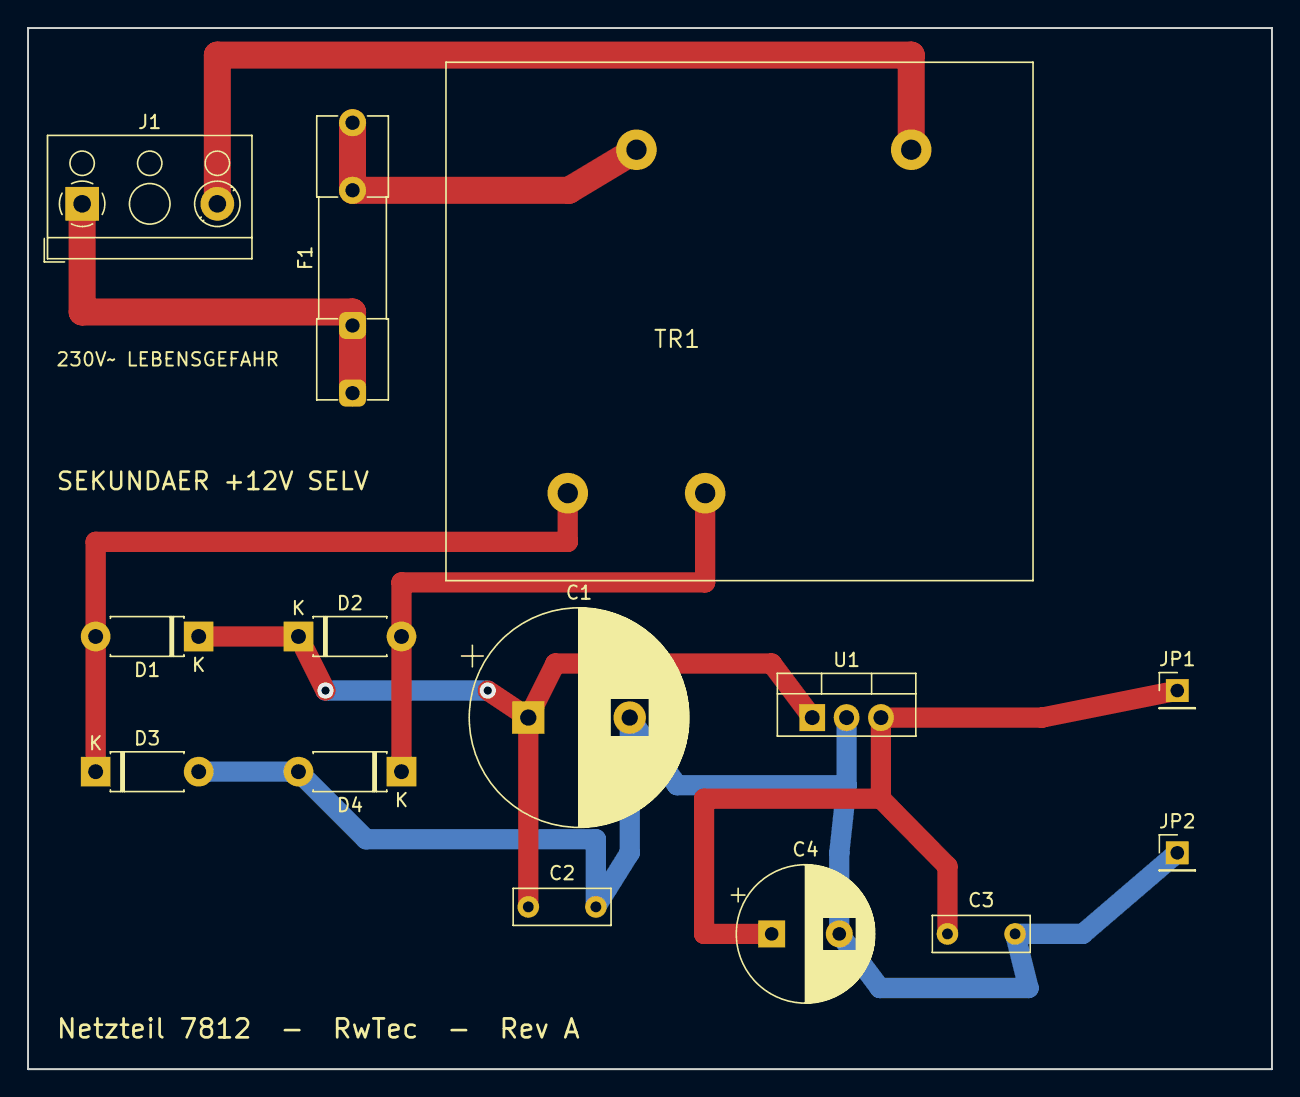
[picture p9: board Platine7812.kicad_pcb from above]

Board: 2 copper layers, 92.0 x 77.0 mm, 14 parts (0 on the bottom side), 8 nets.

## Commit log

2026-09-25 Netzteil 230V~ auf +12V mit 7812 - vollstaendig KI-generiertes KiCad-Projekt
    Schaltplan, Layout, Routing und Produktionsdaten wurden von Claude (Anthropic)
    ueber Claude Code erzeugt - aus einem Vorgabebild und zwei Entscheidungen des
    Anwenders (Trafo auf der Platine, 0,5 A Ausgangsstrom).
    Geprueft: ERC 0 Verstoesse, DRC 0 Verstoesse, 0 unverbundene Anschluesse.
    Kriechstrecke Primaer/Sekundaer >= 6,4 mm per eigener DRC-Regel nachgerechnet.
    Platine 92,2 x 77,2 mm, 2 Lagen, THT, vollstaendig geroutet.
    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
    [Platine7812-B_Cu.gbr, Platine7812-B_Mask.gbr, Platine7812-B_Silkscreen.gbr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]
2026-09-25 MIT-Lizenz ergaenzt
    Gilt fuer Generatorskripte, KiCad-Entwurfsdateien und Produktionsdaten.
    Im README ist zusaetzlich festgehalten, dass der Gewaehrleistungsausschluss
    hier besonders relevant ist: Die Platine fuehrt Netzspannung und ist geprueft,
    aber noch nicht als Hardware aufgebaut.
